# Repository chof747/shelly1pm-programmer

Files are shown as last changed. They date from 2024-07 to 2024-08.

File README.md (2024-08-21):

## shelly1pm-programmer

An adapter to program a Shelly 1 plus with a standard FTDI Programmer

The adapter has the following features:

- A 1.27mm 1x7 pin header to connect to the shelly 1 plus
- A standard header containing the 6 pins needed to program an esp32/esp8266
- An additional 1x2 pin header for the debugging pin
- An UMH3N chip for the auto-reset circutry
- A reset and boot button

## Revision History:

- **v1.0**: Initial version (Produced: 25.07.2024; First assembled: 19.08.2024)

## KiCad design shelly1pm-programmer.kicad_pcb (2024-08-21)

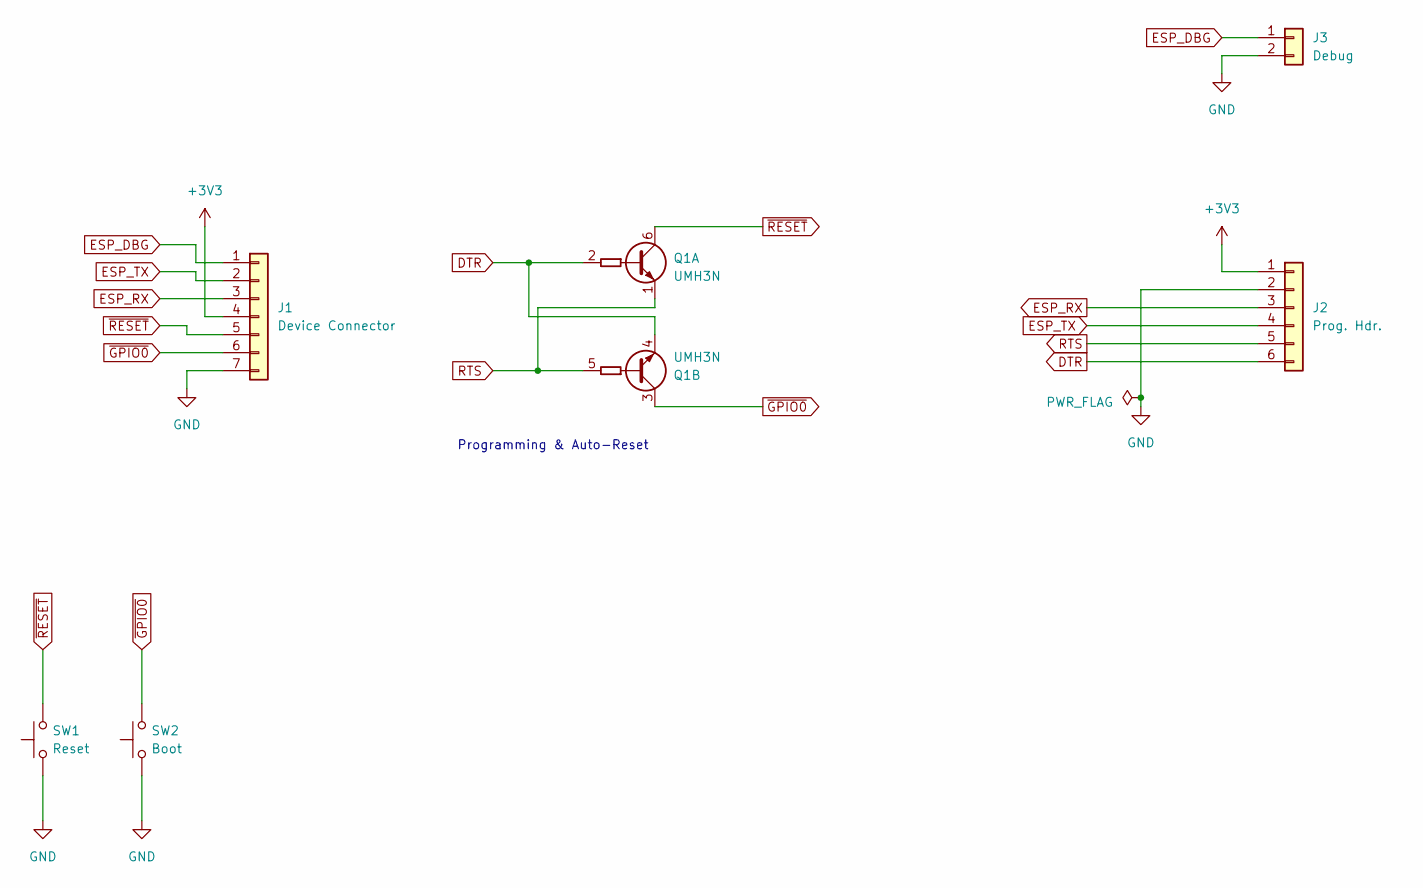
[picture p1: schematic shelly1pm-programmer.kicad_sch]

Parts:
J1: Device Connector; PinHeader_1x07_P1.27mm_Vertical
J2: Prog. Hdr.; PinSocket_1x06_P2.54mm_Horizontal
J3: Debug; PinSocket_1x02_P2.54mm_Vertical
Q1: UMH3N; SOT-363_SC-70-6
SW1: Reset; SW_PUSH_6mm
SW2: Boot; SW_PUSH_6mm

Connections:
+3V3: J1.4, J2.1
DTR: J2.6, Q1.2 (B1), Q1.4 (E2)
ESP_DBG: J1.1, J3.1
ESP_RX: J1.3, J2.3
ESP_TX: J1.2, J2.4
GND: J1.7, J2.2, J3.2, SW1.1, SW2.1
RTS: J2.5, Q1.1 (E1), Q1.5 (B2)
~GPIO0: J1.6, Q1.3 (C2), SW2.2
~RESET: J1.5, Q1.6 (C1), SW1.2

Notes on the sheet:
Programming & Auto-Reset

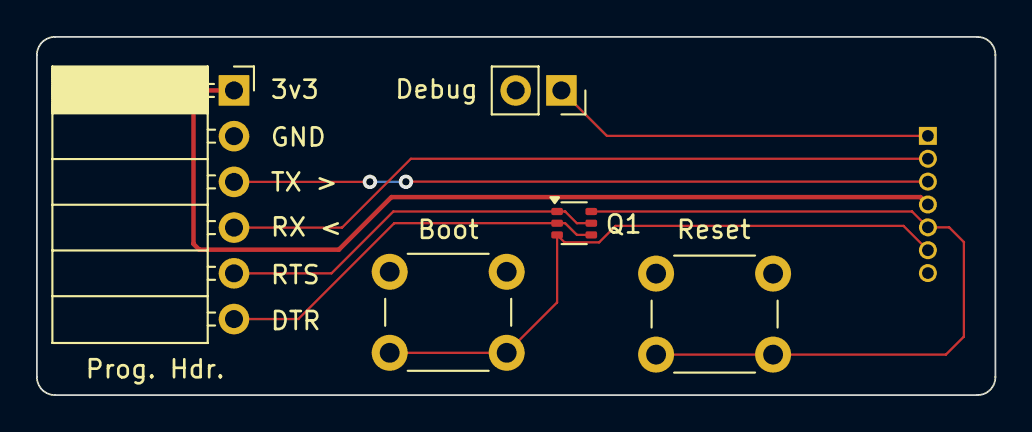
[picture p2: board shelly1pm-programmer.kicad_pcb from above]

Board: 2 copper layers, 53.2 x 19.9 mm, 6 parts (1 on the bottom side), 9 nets.
